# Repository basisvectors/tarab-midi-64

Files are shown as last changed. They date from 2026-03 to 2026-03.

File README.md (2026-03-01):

# **`Tarab Instruments MIDI-64: 16-Knob USB MIDI CC Controller`**

midi_twister_2025-Dec-18_10-33-41AM-000_CustomizedView34942085826

## **`Overview`**

`This controller sends MIDI Control Change (CC) messages over USB. It features 16 knobs, 4 pages of CC assignments (64 CCs total), 4 status LEDs, and 2 buttons. It is recognized as a standard USB MIDI device — no driver installation required.`

**`Controls`**  
**`16 Knobs:`** `Each knob sends a CC value (0–127). The CC number depends on the active page (see table below).`  
**`Left Button (Page Down):`** `Cycles the active page backward (4 → 3 → 2 → 1 → 4...).`  
**`Right Button (Page Up):`** `Cycles the active page forward (1 → 2 → 3 → 4 → 1...).`  
**`Both Buttons (Channel Mode):`** `Press both buttons simultaneously to enter channel mode. The LEDs flash the current MIDI channel in binary. Use Left/Right buttons to increment/decrement the channel (1–16). Channel mode exits automatically after 2 seconds of inactivity.`

**`Quick Start`**

**`1.`** `Connect via USB. The controller appears as a standard MIDI device.`  
**`2.`** `Select it as a MIDI input in your DAW or synth software.`  
**`3.`** `Turn knobs to send CC messages. Use buttons to switch pages or change the MIDI channel.`  
*`Defaults: Page 1 (LED1), MIDI Channel 1. The controller sends on CCs 16–79 across 4 pages.`*

## **`Page Assignments`**

| `Page` | `LED Index` | `CC Range` | `Knob 1–16 Maps To` |
| :---- | :---- | :---- | :---- |
| `1` | `1` | `CC 16–31` | `Knob 1 = CC 16, Knob 2 = CC 17, ... Knob 16 = CC 31` |
| `2` | `2` | `CC 32–47` | `Knob 1 = CC 32, Knob 2 = CC 33, ... Knob 16 = CC 47` |
| `3` | `3` | `CC 48–63` | `Knob 1 = CC 48, Knob 2 = CC 49, ... Knob 16 = CC 63` |
| `4` | `4` | `CC 64–79` | `Knob 1 = CC 64, Knob 2 = CC 65, ... Knob 16 = CC 79` |

## **`LED Indicators & MIDI Channel`** `Four red LEDs sit between the two buttons. During normal use, one LED lights up to indicate the active page (LED 1 = Page 1, LED 2 = Page 2, etc.). In channel mode, the LEDs flash the MIDI channel number in binary: LED 1 = bit 0 (1), LED 2 = bit 1 (2), LED 3 = bit 2 (4), LED 4 = bit 3 (8). Examples: Channel 1 = LED 1 only. Channel 3 = LEDs 1+2. Channel 5 = LEDs 1+3. Channel 10 = LEDs 2+4. Channel 16 = all four LEDs.`

## **`Knob Pickup (Anti-Jump)`** `When you switch pages, knobs are locked to prevent value jumps. A knob will not send CC data on the new page until you turn it past the previously stored value for that page. This lets you switch pages safely without accidentally changing parameters.`

## 

## 

## 

## **`Ableton Live MIDI Remote Script Setup`**

[`MIDITwister.zip`](https://drive.google.com/file/d/18PWd5HxEwH-kTtX2BjnFFBZiqqTWufoS/view?usp=drive_link) `- Google Drive`

[`Creating your own Control Surface script – Ableton`](https://help.ableton.com/hc/en-us/articles/206240184-Creating-your-own-Control-Surface-script)

`Since not all MIDI controllers have a native Control Surface in Live, you can create your own using the UserConfiguration.txt for basic functions like Device Control, Track Control and Transport Control.`

`The UserConfiguration.txt file and directions on how to use it are found in the User Remote Scripts folder, which is stored in Live's Preferences folder:`

`Mac: HD:/Users/[Username]/Library/Preferences/Ableton/Live x.x.x/User Remote Scripts`

`Windows: C:\Users\[Username]\AppData\Roaming\Ableton\Live x.x.x\Preferences\User Remote Scripts`

`Note: These folders are hidden by default.`  
`The User Remote Scripts Folder`

`In the User Remote Scripts folder, you will find two files, the InstantMappings-HowTo.txt file and the UserConfiguration.txt file.`

`The InstantMappings-HowTo.txt file describes how and where to save the file.`  
`The UserConfiguration.txt file contains instructions on how to edit the file itself so that it works with your MIDI controller.`   
   
`You will need to know on what MIDI Channel your controller sends data, and you will also need to know the specific MIDI CC assignments for the various pads, encoders, and sliders.`

`One quick way to find this out is to make a MIDI remote control assignment in Live and note down the corresponding CC value. Alternatively, you can use Snoize MIDI Monitor for Mac, or OBDS MIDI Monitor for PC.`

## `.`

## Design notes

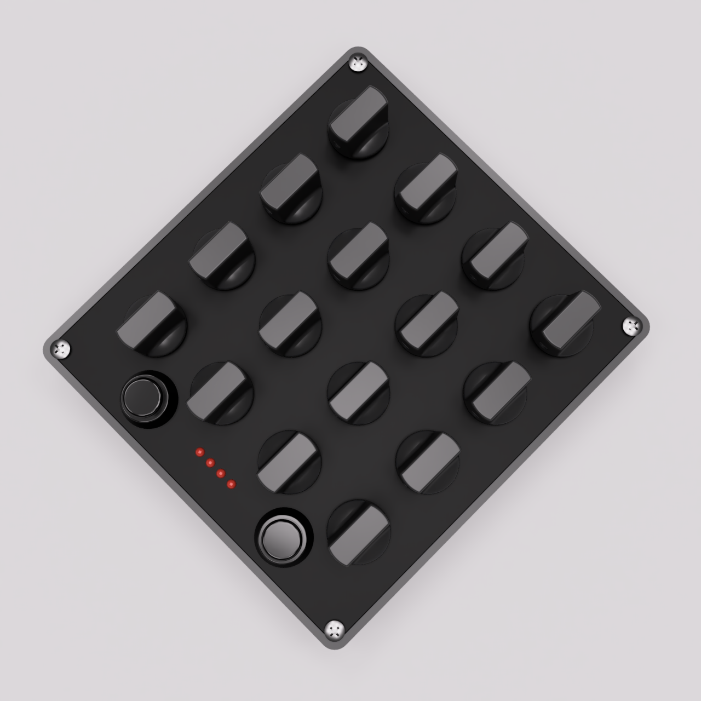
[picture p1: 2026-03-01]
hardware/mockups/bf4e88f0-ecdf-42c0-a8b4-4a1e95d9abff.PNG

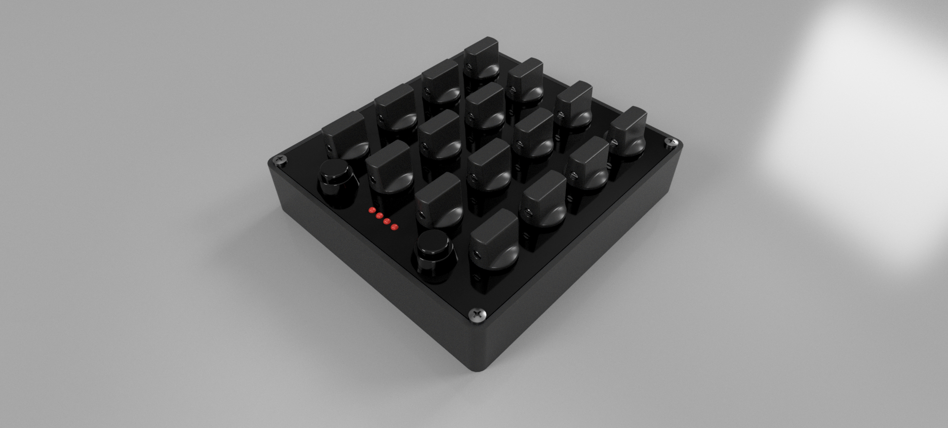
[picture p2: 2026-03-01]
hardware/mockups/midi twister v142.png

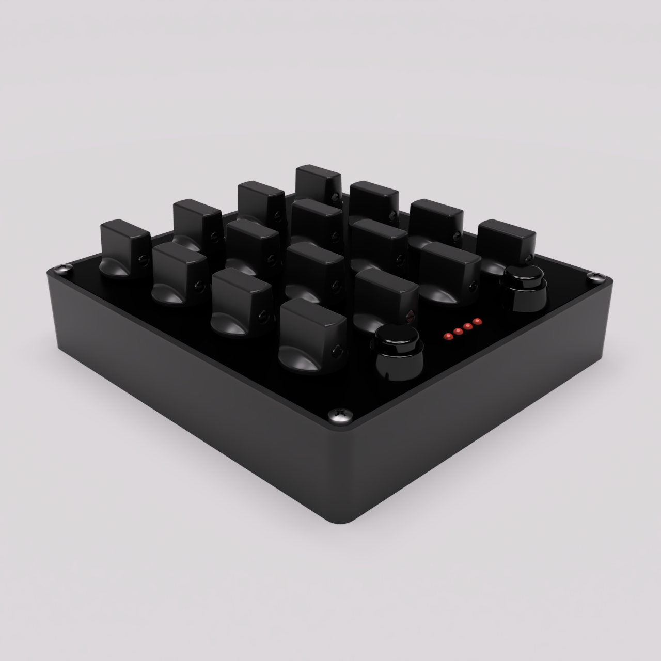
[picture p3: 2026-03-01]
hardware/mockups/midi_twister_2025-Dec-18_10-33-41AM-000_CustomizedView34942085826.png

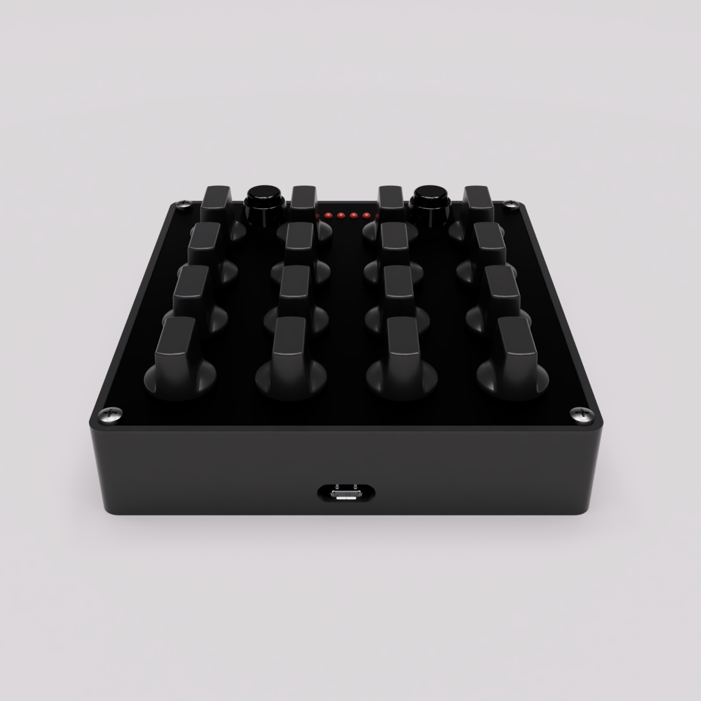
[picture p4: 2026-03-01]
hardware/mockups/a330c05e-12fd-442b-8131-1a8d69ce1747.PNG

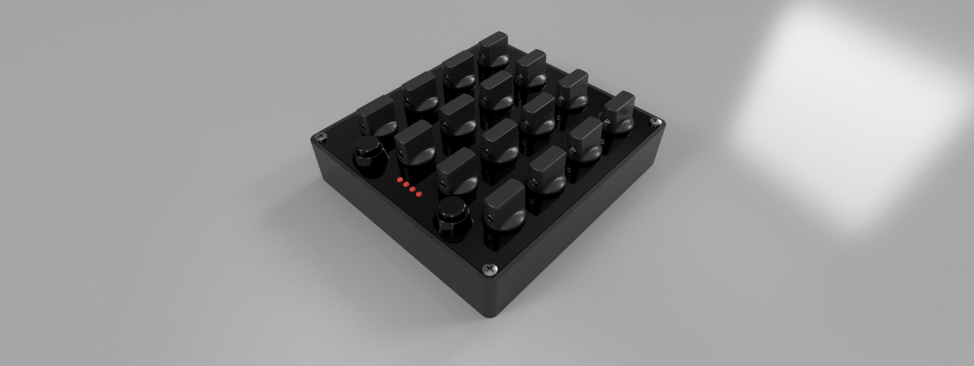
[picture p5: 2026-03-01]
hardware/mockups/midi twister v14.png

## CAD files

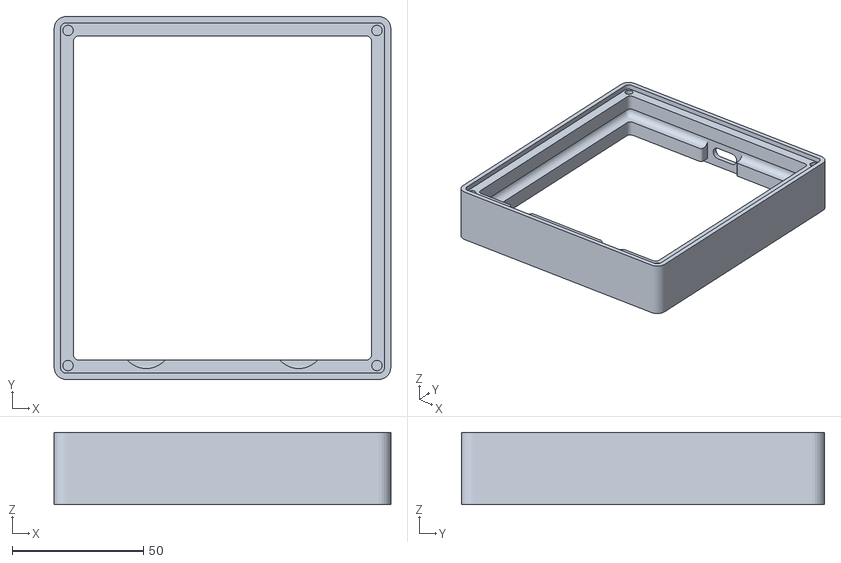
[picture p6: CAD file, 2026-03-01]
hardware/production_files/side_panel.stl
128.4 x 138.4 x 27.5

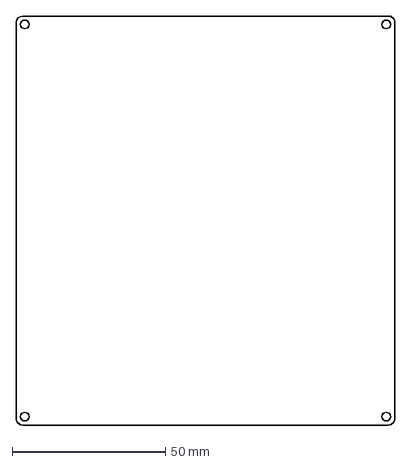
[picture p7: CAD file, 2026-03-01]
hardware/production_files/midi twister v13 - bottom.dxf
123.3 x 133.3 mm

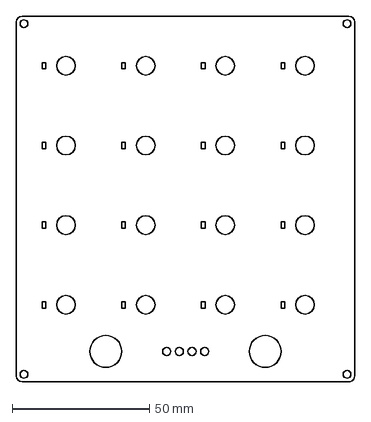
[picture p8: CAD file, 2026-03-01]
hardware/production_files/midi twister v18 - top.dxf
123.3 x 133.3 mm

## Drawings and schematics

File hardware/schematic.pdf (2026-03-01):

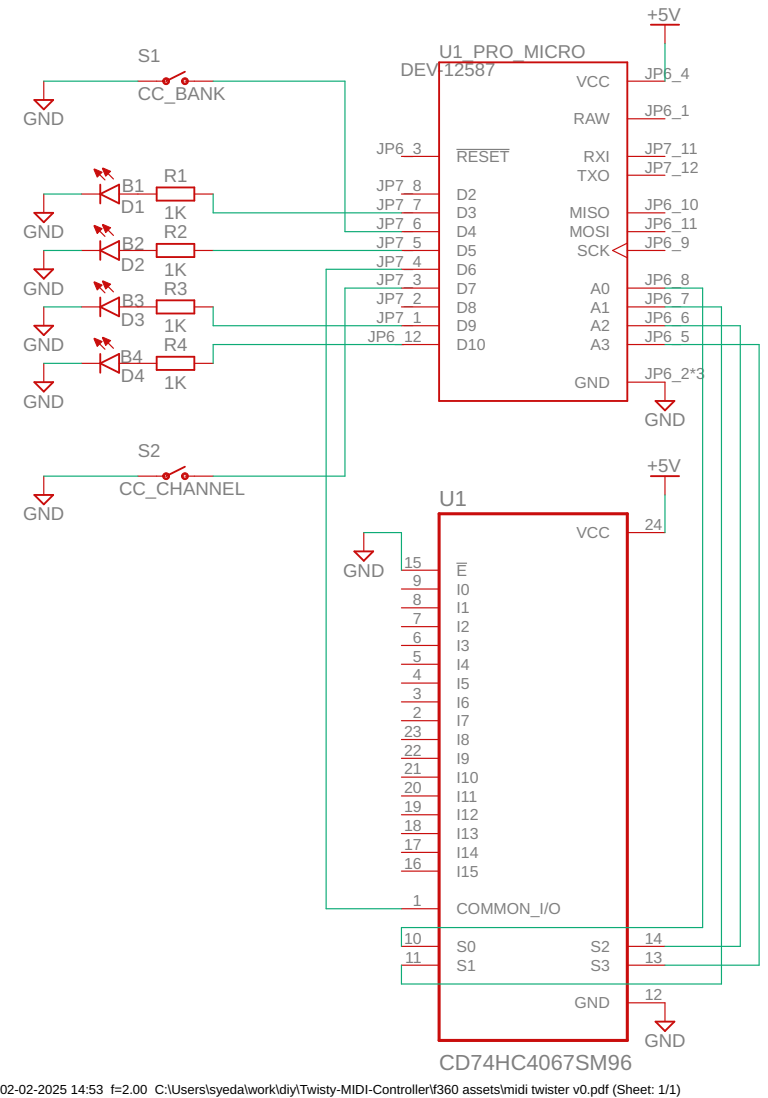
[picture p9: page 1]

02-02-2025 14:53 f=2.00 C:\Users\syeda\work\diy\Twisty-MIDI-Controller\f360 assets\midi twister v0.pdf (Sheet: 1/1)

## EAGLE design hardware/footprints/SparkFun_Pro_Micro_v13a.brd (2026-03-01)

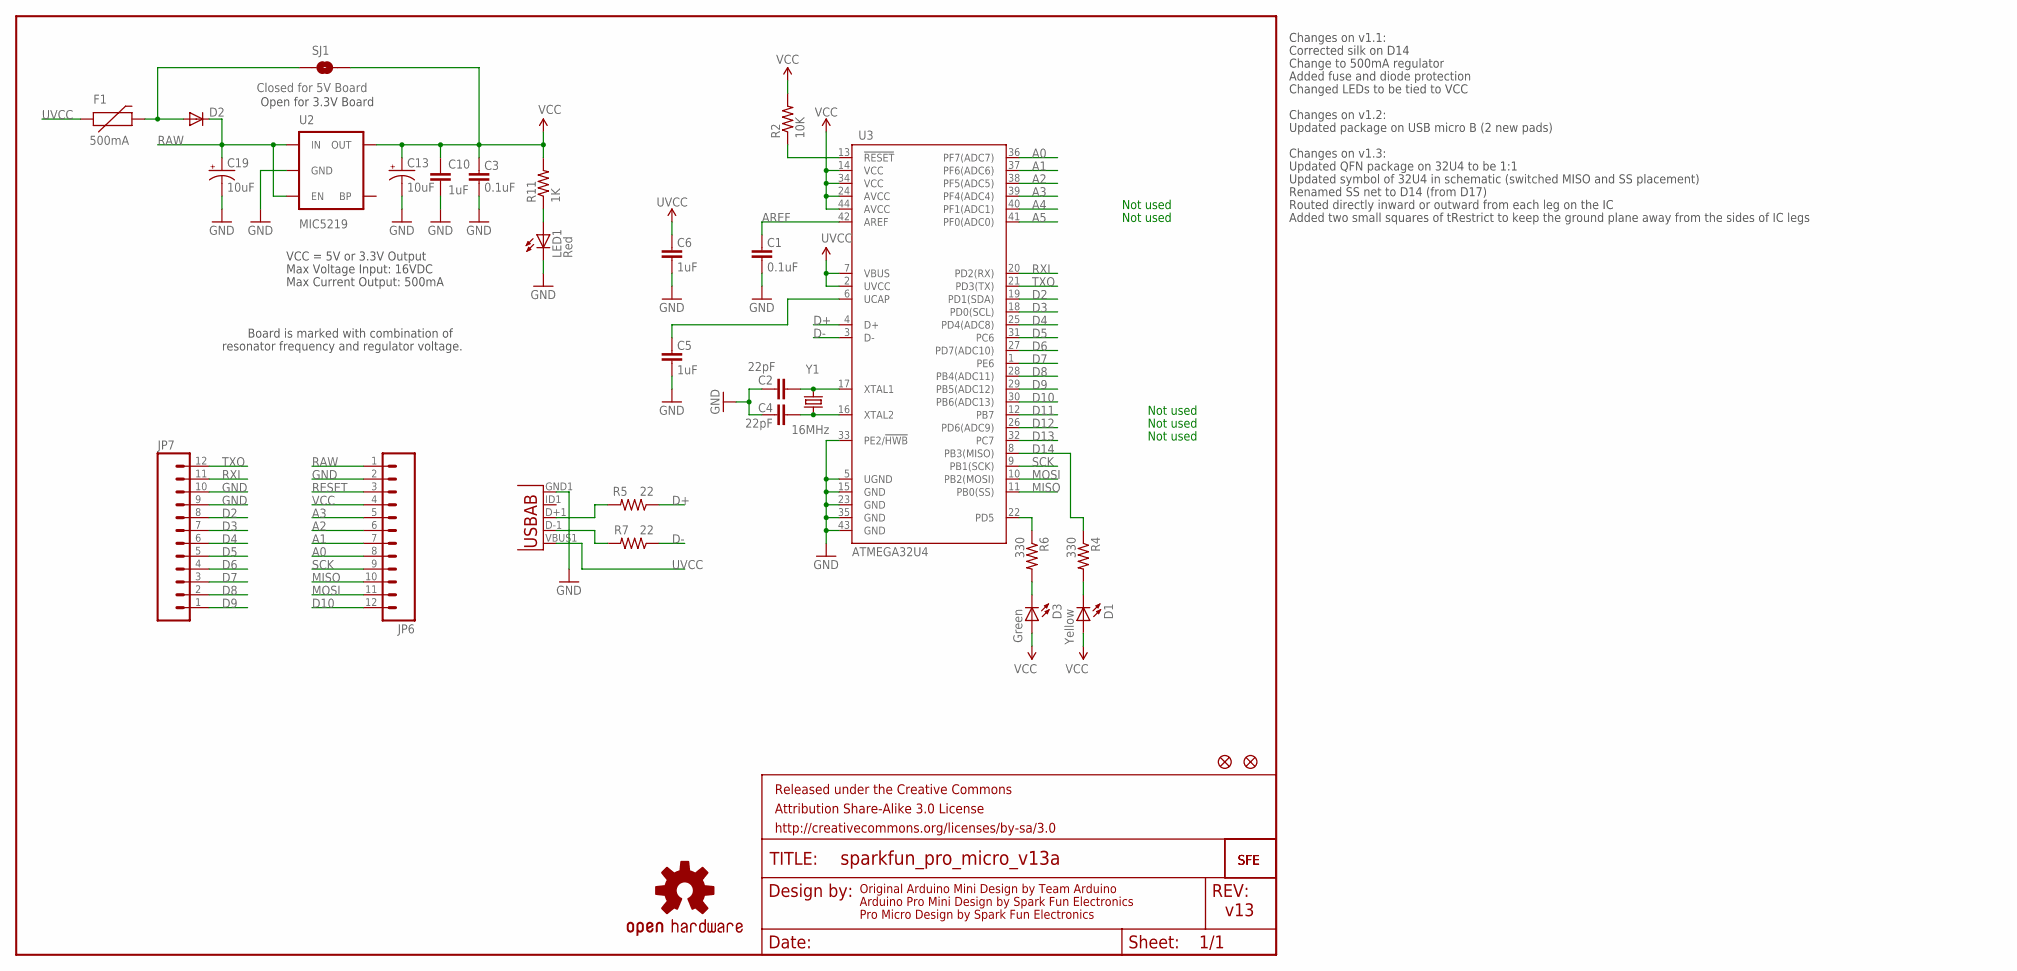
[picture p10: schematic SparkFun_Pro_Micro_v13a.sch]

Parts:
C1, C3: 0.1uF; 0603-CAP
C2, C4: 22pF; 0603-CAP
C5, C6, C10: 1uF; 0603-CAP
C13, C19: 10uF; EIA3216
D1: Yellow; LED-0603
D2: DIODESOD; SOD-323
D3: Green; LED-0603
F1: 500mA; PTC-1206
FRAME1: FRAME-LETTER; CREATIVE_COMMONS
JP1, JP2: FIDUCIALUFIDUCIAL; MICRO-FIDUCIAL
JP6, JP7: M12PTH; 1X12
LED1: Red; LED-0603
R2: 10K; 0603-RES
R4, R6: 330; 0603-RES
R5, R7: 22; 0603-RES
R11: 1K; 0603-RES
SJ1: Closed for 5V Board; SJ_2S
U2: MIC5219; SOT23-5
U3: ATMEGA32U4; QFN-44-NOPAD_1:1-OUTFAKES
U$1: LOGO-SFESK; SFE-LOGO-FLAME
U$3: OSHW-LOGOS; OSHW-LOGO-S
U$11: LOGO-SFENEW; SFE-NEW-WEBLOGO
X1: USB-ABIN&OUT; USB-AB-MICRO-SMD-V03-IN&OUT
Y1: 16MHz; CRYSTAL-SMD-5X3

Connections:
A0: JP6.8, U3.36 (PF7(ADC7))
A1: JP6.7, U3.37 (PF6(ADC6))
A2: JP6.6, U3.38 (PF5(ADC5))
A3: JP6.5, U3.39 (PF4(ADC4))
A4: U3.40 (PF1(ADC1))
A5: U3.41 (PF0(ADC0))
AREF: C1.2, U3.42 (AREF)
D2: JP7.8, U3.19 (PD1(SDA))
D3: JP7.7, U3.18 (PD0(SCL))
D4: JP7.6, U3.25 (PD4(ADC8))
D5: JP7.5, U3.31 (PC6)
D6: JP7.4, U3.27 (PD7(ADC10))
D7: JP7.3, U3.1 (PE6)
D8: JP7.2, U3.28 (PB4(ADC11))
D9: JP7.1, U3.29 (PB5(ADC12))
D10: JP6.12, U3.30 (PB6(ADC13))
D11: U3.12 (PB7)
D12: U3.26 (PD6(ADC9))
D13: U3.32 (PC7)
D14: R4.1, U3.8 (PB3(MISO))
D+: R5.1, U3.4 (D+)
D-: R7.1, U3.3 (D-)
GND: C1.1, C2.2, C3.1, C4.2, C5.1, C6.1, C10.2, C13.C (-), C19.C (-), JP6.2, JP7.9, JP7.10, LED1.C, U2.2 (GND), U3.5 (UGND), U3.15 (GND), U3.23 (GND), U3.33 (PE2/!HWB), U3.35 (GND), U3.43 (GND), X1.GND1 (GND)
MISO: JP6.10, U3.11 (PB0(SS))
MOSI: JP6.11, U3.10 (PB2(MOSI))
unnamed: C4.1, U3.16 (XTAL2), Y1.1
unnamed: C2.1, U3.17 (XTAL1), Y1.3 (2)
unnamed: D2.2 (A), F1.2, SJ1.1
unnamed: C5.2, U3.6 (UCAP)
unnamed: D1.C, R4.2
unnamed: R7.2, X1.D-1 (D-)
unnamed: D3.C, R6.2
unnamed: R5.2, X1.D+1 (D+)
unnamed: LED1.A, R11.1
RAW: C19.A (+), D2.1 (C), JP6.1, U2.1 (IN), U2.3 (EN)
RESET: JP6.3, R2.1, U3.13 (!RESET)
RXI: JP7.11, U3.20 (PD2(RX))
SCK: JP6.9, U3.9 (PB1(SCK))
TXLED: R6.1, U3.22 (PD5)
TXO: JP7.12, U3.21 (PD3(TX))
UVCC: C6.2, F1.1, U3.2 (UVCC), U3.7 (VBUS), X1.VBUS1 (VBUS)
VCC: C3.2, C10.1, C13.A (+), D1.A, D3.A, JP6.4, R2.2, R11.2, SJ1.2, U2.5 (OUT), U3.14 (VCC), U3.24 (AVCC), U3.34 (VCC), U3.44 (AVCC)

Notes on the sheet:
Original Arduino Mini Design by Team Arduino
Arduino Pro Mini Design by Spark Fun Electronics
Max Voltage Input: 16VDC
Max Current Output: 500mA
Board is marked with combination of
resonator frequency and regulator voltage.
VCC = 5V or 3.3V Output
Not used
Pro Micro Design by Spark Fun Electronics
Changes on v1.1:
Corrected silk on D14
Change to 500mA regulator
Open for 3.3V Board
Added fuse and diode protection
Changed LEDs to be tied to VCC
Changes on v1.2:
Updated package on USB micro B (2 new pads)
Changes on v1.3:
Updated QFN package on 32U4 to be 1:1
Updated symbol of 32U4 in schematic (switched MISO and SS placement)
Renamed SS net to D14 (from D17)
Routed directly inward or outward from each leg on the IC
Added two small squares of tRestrict to keep the ground plane away from the sides of IC legs
v13

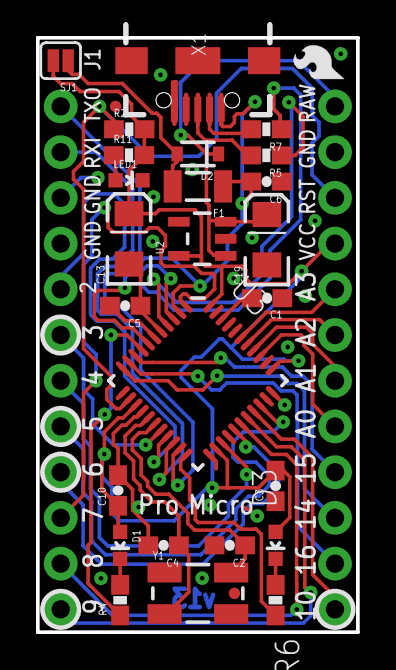
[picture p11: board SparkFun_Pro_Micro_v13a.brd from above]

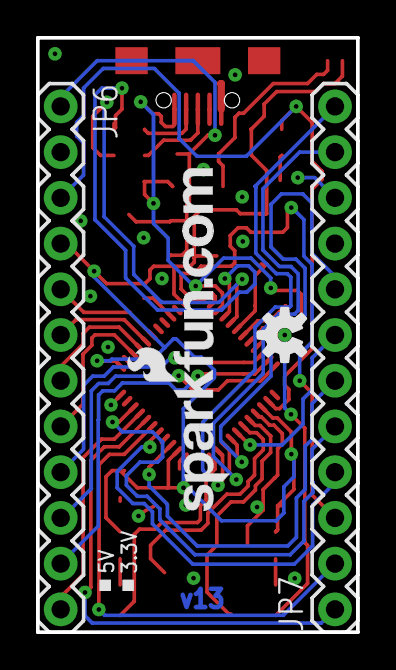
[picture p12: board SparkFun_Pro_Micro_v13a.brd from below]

Board: 2 copper layers, 17.8 x 33.0 mm, 33 parts (4 on the bottom side), 37 nets.

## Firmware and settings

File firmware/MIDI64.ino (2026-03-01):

// based on code and hardware implementation from 
// https://github.com/rheslip/Twisty-MIDI-Controller

#include "MIDIUSB.h"

#define NPOTS 16 // number of pots
#define NPAGES 4 // number of pages
uint16_t pot[NPOTS]; // pot readings
uint16_t lastpots[NPOTS]; // old pot readings
bool potlock[NPOTS]; // when pots are locked it means they must change by MIN_POT_CHANGE to register
uint8_t CC[NPOTS]; // CC values
uint8_t pageCC[NPAGES][NPOTS]; // CC values stored per page - for pot pickup
uint8_t channel=0; // MIDI channel - starts at 0
uint8_t page=0; // CC page 0-3
uint8_t leds=0;
long button2timer;
bool shift=0;  // alt button mode
int mode;      // CC message mode or LFO mode
// button debounce variables
uint8_t button1State = HIGH;
uint8_t button1LastState = HIGH;
unsigned long button1LastDebounceTime = 0;
uint8_t button2State = HIGH;
uint8_t button2LastState = HIGH;
unsigned long button2LastDebounceTime = 0;
#define CCMODE 0

#define RED_PIN 3 // LED output pins
#define ORANGE_PIN 5
#define YELLOW_PIN 9
#define GREEN_PIN 10
#define RED 1   // LED bit masks
#define ORANGE 2
#define YELLOW 8
#define GREEN 4
#define LEDFLASH 100 // flash rate
#define BUTTON1 4  // change bank button
#define BUTTON2 7  // change channel button
#define BUTTON2_TIME 2000 // increment timer
#define DEBOUNCE 10 // button debounce time in ms

#define MUX_IN A7 // port we read values from MUX
#define BASE_CC 16  // lowest CC number to use
#define MIN_POT_CHANGE 25 // pot reading must change by this in order to register


#define POT_AVERAGING 5 //average to use in LFO page 

// midi related stuff
// First parameter is the event type (0x09 = note on, 0x08 = note off).
// Second parameter is note-on/note-off, combined with the channel.
// Channel can be anything between 0-15. Typically reported to the user as 1-16.
// Third parameter is the note number (48 = middle C).
// Fourth parameter is the velocity (64 = normal, 127 = fastest).

void noteOn(byte channel, byte pitch, byte velocity) {
  midiEventPacket_t noteOn = {0x09, 0x90 | channel, pitch, velocity};
  MidiUSB.sendMIDI(noteOn);
}

void noteOff(byte channel, byte pitch, byte velocity) {
  midiEventPacket_t noteOff = {0x08, 0x80 | channel, pitch, velocity};
  MidiUSB.sendMIDI(noteOff);
}

// First parameter is the event type (0x0B = control change).
// Second parameter is the event type, combined with the channel.
// Third parameter is the control number number (0-119).
// Fourth parameter is the control value (0-127).

void controlChange(byte channel, byte control, byte value) {
  midiEventPacket_t event = {0x0B, 0xB0 | channel, control, value};
  MidiUSB.sendMIDI(event);
}


// set analog mux address for reading pots
void muxaddr(int addr) {
  digitalWrite(A0, addr & 1);
  digitalWrite(A1, addr & 2);
  digitalWrite(A2, addr & 4);
  digitalWrite(A3, addr & 8);  
}

// flag all pot values as locked ie they have to change more than MIN_POT_CHANGE to register
void lockpots(void) {
  for (int i=0; i<NPOTS;++i) potlock[i]=1;
}

// sample analog pot input and do filtering. 
// if pots are locked, change value only if pot crosses the stored CC value for the current page (pot pickup)
uint16_t sample_pot(uint8_t potnum) {
    int val=0;
    muxaddr(potnum);
    for (int j=0; j<POT_AVERAGING;++j) val+=analogRead(MUX_IN); // read the A/D a few times and average for a more stable value
    val=val/POT_AVERAGING;
    if (potlock[potnum]) {
      // pot pickup: check if current pot value has crossed the stored CC value for this page
      uint8_t currentCC = val / 8; // convert to CC range 0-127
      uint8_t storedCC = pageCC[page][potnum];
      uint8_t lastCC = lastpots[potnum] / 8;
      
      // unlock if pot has crossed the stored value (moved from one side to the other)
      if ((lastCC <= storedCC && currentCC >= storedCC) || (lastCC >= storedCC && currentCC <= storedCC)) {
        potlock[potnum]=0;   // flag pot no longer locked
        pot[potnum]=lastpots[potnum]=val; // save the new reading
      }
      else {
        lastpots[potnum]=val; // update last reading but keep pot locked
        val=pot[potnum]; // return the old locked value
      }
    }
    else {
      if (abs(lastpots[potnum]-val) > 7) lastpots[potnum]=val; // even if pot is unlocked, make sure pot has moved at least 8 counts so CC values don't jump around
      else val=lastpots[potnum];
      pot[potnum]=val; // pot is unlocked so save the reading
    }
    return val;
}

// set LEDs state based on bit mask
void setleds(uint8_t setting) {
  if (setting &1) digitalWrite(RED_PIN, 1);
  else digitalWrite(RED_PIN, 0); 
  if (setting &2) digitalWrite(ORANGE_PIN, 1);
  else digitalWrite(ORANGE_PIN, 0); 
  if (setting &4) digitalWrite(YELLOW_PIN, 1);
  else digitalWrite(YELLOW_PIN, 0); 
  if (setting &8) digitalWrite(GREEN_PIN, 1);
  else digitalWrite(GREEN_PIN, 0); 
}


void setup() {
  Serial.begin(115200);
  pinMode(LED_BUILTIN, OUTPUT);
  pinMode(A0, OUTPUT);    // mux addresses
  pinMode(A1, OUTPUT);  
  pinMode(A2, OUTPUT);  
  pinMode(A3, OUTPUT);
  pinMode(BUTTON1, INPUT_PULLUP);  
  pinMode(BUTTON2, INPUT_PULLUP);    
  pinMode(RED_PIN, OUTPUT);  
  pinMode(GREEN_PIN, OUTPUT);  
  pinMode(ORANGE_PIN, OUTPUT);  
  pinMode(YELLOW_PIN, OUTPUT); 
  setleds(1<<page);  // show CC page number using LED - red=1, orange=2, yellow=3, green=4

  for (int i=0; i<NPOTS;++i) {
    sample_pot(i); // initialize pot settings
    uint8_t initCC = pot[i] / 8; // convert to CC range
    for (int p=0; p<NPAGES; ++p) {
      pageCC[p][i] = initCC; // initialize all pages with current pot positions
    }
  }
  lockpots(); // set high initial movement threshold
  mode=CCMODE;
}
  
void loop() {
  uint8_t reading;
  int i,j;


  // --- New page and channel logic ---
  uint8_t button1Reading = digitalRead(BUTTON1);
  uint8_t button2Reading = digitalRead(BUTTON2);

  // Debounce both buttons
  if (button1Reading != button1LastState) button1LastDebounceTime = millis();
  if (button2Reading != button2LastState) button2LastDebounceTime = millis();

  bool button1Pressed = false;
  bool button2Pressed = false;
  static bool channelMode = false;

  if ((millis() - button1LastDebounceTime) > DEBOUNCE) {
    if (button1Reading != button1State) {
      button1State = button1Reading;
      if (button1State == LOW) button1Pressed = true;
    }
  }
  if ((millis() - button2LastDebounceTime) > DEBOUNCE) {
    if (button2Reading != button2State) {
      button2State = button2Reading;
      if (button2State == LOW) button2Pressed = true;
    }
  }
  button1LastState = button1Reading;
  button2LastState = button2Reading;

  // Both buttons pressed: enter/exit channel mode
  static bool prevBothPressed = false;
  bool bothPressed = (button1Reading == LOW && button2Reading == LOW);
  if (bothPressed && !prevBothPressed) {
    channelMode = !channelMode; // toggle channel mode
    button2timer = millis();
  }
  prevBothPressed = bothPressed;

  if (!channelMode) {
    // Page up/down
    if (button2Pressed && !bothPressed) {
      page++;
      if (page > 3) page = 0;
      lockpots();
      setleds(1<<page);
    }
    if (button1Pressed && !bothPressed) {
      if (page == 0) page = 3; else page--;
      lockpots();
      setleds(1<<page);
    }
  } else {
    // Channel change mode
    // Show channel number while in channel mode
    if ((millis()/LEDFLASH) & 1) setleds(channel+1);
    else setleds(0);
    // Increment channel with button1, decrement with button2
    if (button1Pressed && !bothPressed) {
      channel = (channel + 1) & 0xf;
      setleds(channel+1);
      button2timer = millis();
    }
    if (button2Pressed && !bothPressed) {
      channel = (channel == 0) ? 15 : channel - 1;
      setleds(channel+1);
      button2timer = millis();
    }
    // Exit channel mode if no button pressed for BUTTON2_TIME
    if ((millis() - button2timer) > BUTTON2_TIME && !bothPressed && !button1Pressed && !button2Pressed) {
      channelMode = false;
      setleds(1<<page);
    }
  }
      
  if (mode==CCMODE ) { // send CC messages if pots change
    for (i=0;i<NPOTS;++i) {
      if (CC[i] != (reading=sample_pot(i)/8)) { // convert pot value 0-1023 to CC value 0-127
       CC[i]=reading;
        pageCC[page][i]=reading; // store CC value for this page for pot pickup
        controlChange(channel,BASE_CC+i+page*16, CC[i]);
        MidiUSB.flush();      // forces message to be sent now
      }
    }
  }
  
}

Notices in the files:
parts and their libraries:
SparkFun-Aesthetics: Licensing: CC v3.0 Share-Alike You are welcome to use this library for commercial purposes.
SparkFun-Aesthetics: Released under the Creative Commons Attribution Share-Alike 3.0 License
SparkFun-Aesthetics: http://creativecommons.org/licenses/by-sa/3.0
